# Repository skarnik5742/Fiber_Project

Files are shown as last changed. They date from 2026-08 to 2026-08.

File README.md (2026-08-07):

| Supported Targets | ESP32 | ESP32-C2 | ESP32-C3 | ESP32-C5 | ESP32-C6 | ESP32-C61 | ESP32-H2 | ESP32-H21 | ESP32-H4 | ESP32-P4 | ESP32-S2 | ESP32-S3 |
| --- | ----- | --- | --- | --- | --- | --- | --- | --- | --- | --- | --- | --- |

# Blink Example

(See the README.md file in the upper level 'examples' directory for more information about examples.)

This example demonstrates how to blink a LED by using the GPIO driver or using the [led_strip](https://components.espressif.com/component/espressif/led_strip) library if the LED is addressable e.g. [WS2812](https://cdn-shop.adafruit.com/datasheets/WS2812B.pdf). The `led_strip` library is installed via [component manager](main/idf_component.yml).

## How to Use Example

Before project configuration and build, be sure to set the correct chip target using `idf.py set-target <chip_name>`.

### Hardware Required

* A development board with normal LED or addressable LED on-board (e.g., ESP32-S3-DevKitC, ESP32-C6-DevKitC etc.)
* A USB cable for Power supply and programming

See [Development Boards](https://www.espressif.com/en/products/devkits) for more information about it.

### Configure the Project

Open the project configuration menu (`idf.py menuconfig`).

In the `Example Configuration` menu:

* Select the LED type in the `Blink LED type` option.
  * Use `GPIO` for regular LED
  * Use `LED strip` for addressable LED
* If the LED type is `LED strip`, select the backend peripheral
  * `RMT` is only available for ESP targets with RMT peripheral supported
  * `SPI` is available for all ESP targets
* Set the GPIO number used for the signal in the `Blink GPIO number` option.
* Set the blinking period in the `Blink period in ms` option.

### Build and Flash

Run `idf.py -p PORT flash monitor` to build, flash and monitor the project.

(To exit the serial monitor, type ``Ctrl-]``.)

See the [Getting Started Guide](https://docs.espressif.com/projects/esp-idf/en/latest/get-started/index.html) for full steps to configure and use ESP-IDF to build projects.

## Example Output

As you run the example, you will see the LED blinking, according to the previously defined period. For the addressable LED, you can also change the LED color by setting the `led_strip_set_pixel(led_strip, 0, 16, 16, 16);` (LED Strip, Pixel Number, Red, Green, Blue) with values from 0 to 255 in the [source file](main/blink_example_main.c).

```text
I (315) example: Example configured to blink addressable LED!
I (325) example: Turning the LED OFF!
I (1325) example: Turning the LED ON!
I (2325) example: Turning the LED OFF!
I (3325) example: Turning the LED ON!
I (4325) example: Turning the LED OFF!
I (5325) example: Turning the LED ON!
I (6325) example: Turning the LED OFF!
I (7325) example: Turning the LED ON!
I (8325) example: Turning the LED OFF!
```

Note: The color order could be different according to the LED model.

The pixel number indicates the pixel position in the LED strip. For a single LED, use 0.

## Troubleshooting

* If the LED isn't blinking, check the GPIO or the LED type selection in the `Example Configuration` menu.

For any technical queries, please open an [issue](https://github.com/espressif/esp-idf/issues) on GitHub. We will get back to you soon.

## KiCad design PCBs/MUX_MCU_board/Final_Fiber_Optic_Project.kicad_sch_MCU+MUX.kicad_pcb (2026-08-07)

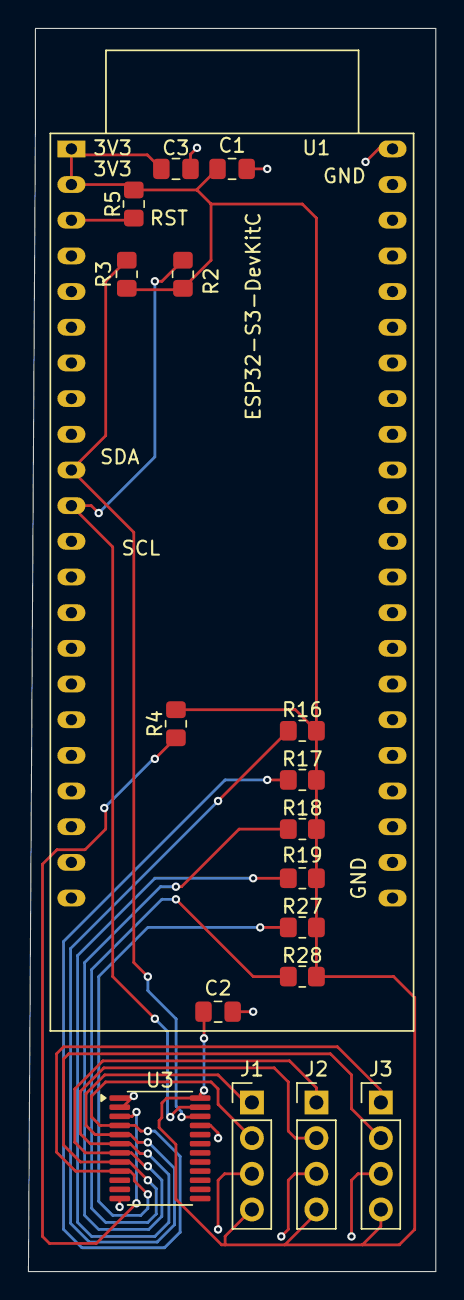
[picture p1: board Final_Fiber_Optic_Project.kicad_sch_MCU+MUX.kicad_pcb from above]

Board: 2 copper layers, 29.0 x 88.5 mm, 18 parts (0 on the bottom side), 12 nets.

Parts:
C1, C2: 100nF; C_0805_2012Metric_Pad1.18x1.45mm_HandSolder
C3: 10uF; C_0805_2012Metric_Pad1.18x1.45mm_HandSolder
J1, J2, J3: Conn_01x04_Socket; PinHeader_1x04_P2.54mm_Vertical
R2, R3, R4, R5: 10kOhm; R_0805_2012Metric_Pad1.20x1.40mm_HandSolder
R16, R17, R18, R19, R27, R28: 2kOhm; R_0805_2012Metric_Pad1.20x1.40mm_HandSolder
U1: ESP32-S3-DevKitC
U3: TCA9548APWR; TSSOP-24_4.4x7.8mm_P0.65mm

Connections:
GND: C1.2, C2.2, C3.2, J1.3, J2.3, J3.3, U1.22 (GND), U1.23 (GND), U1.24 (GND), U1.44 (GND), U3.1 (A0), U3.2 (A1), U3.12 (GND), U3.21 (A2)
unnamed: J1.1, R16.1, U3.5 (SC0)
unnamed: J1.2, R17.2, U3.4 (SD0)
unnamed: C1.1, C2.1, C3.1, J1.4, J2.4, J3.4, R2.1, R3.1, R4.1, R5.1, R16.2, R17.1, R18.1, R19.2, R27.2, R28.2, U1.1 (3V3), U1.2 (3V3), U3.24 (VCC)
unnamed: J2.1, R18.2, U3.7 (SC1)
unnamed: J2.2, R19.1, U3.6 (SD1)
unnamed: J3.1, R27.1, U3.9 (SC2)
unnamed: J3.2, R28.1, U3.8 (SD2)
unnamed: R5.2, U1.3 (CHIP_PU)
unnamed: R3.2, U1.10 (GPIO17/ADC2_CH6), U3.22 (SCL)
unnamed: R2.2, U1.11 (GPIO18/ADC2_CH7), U3.23 (SDA)
unnamed: R4.2, U3.3 (~RESET)

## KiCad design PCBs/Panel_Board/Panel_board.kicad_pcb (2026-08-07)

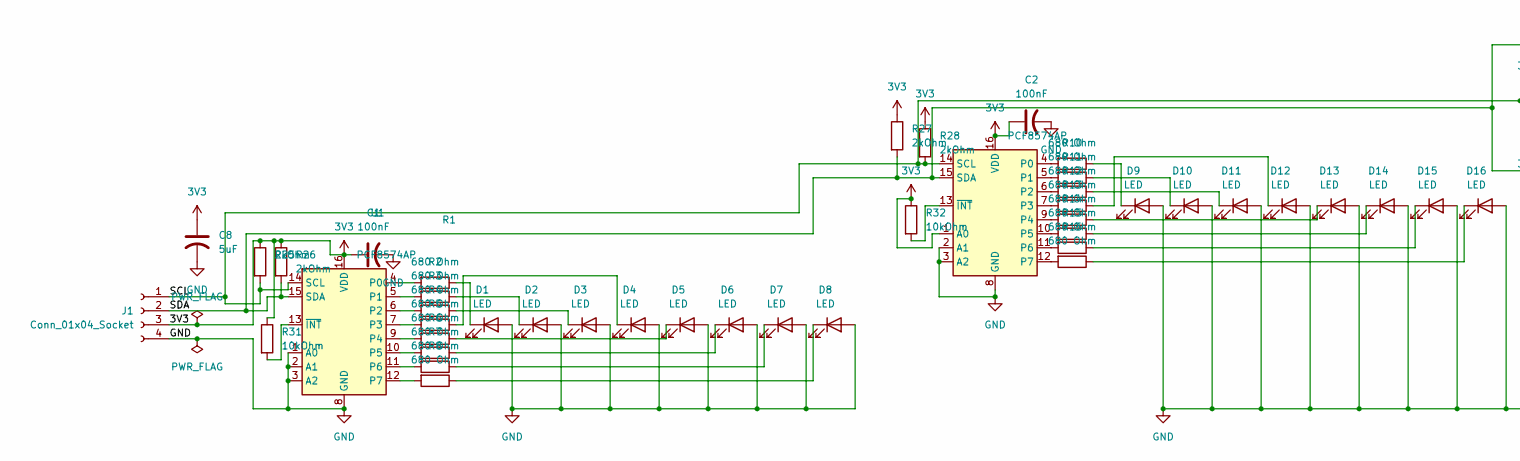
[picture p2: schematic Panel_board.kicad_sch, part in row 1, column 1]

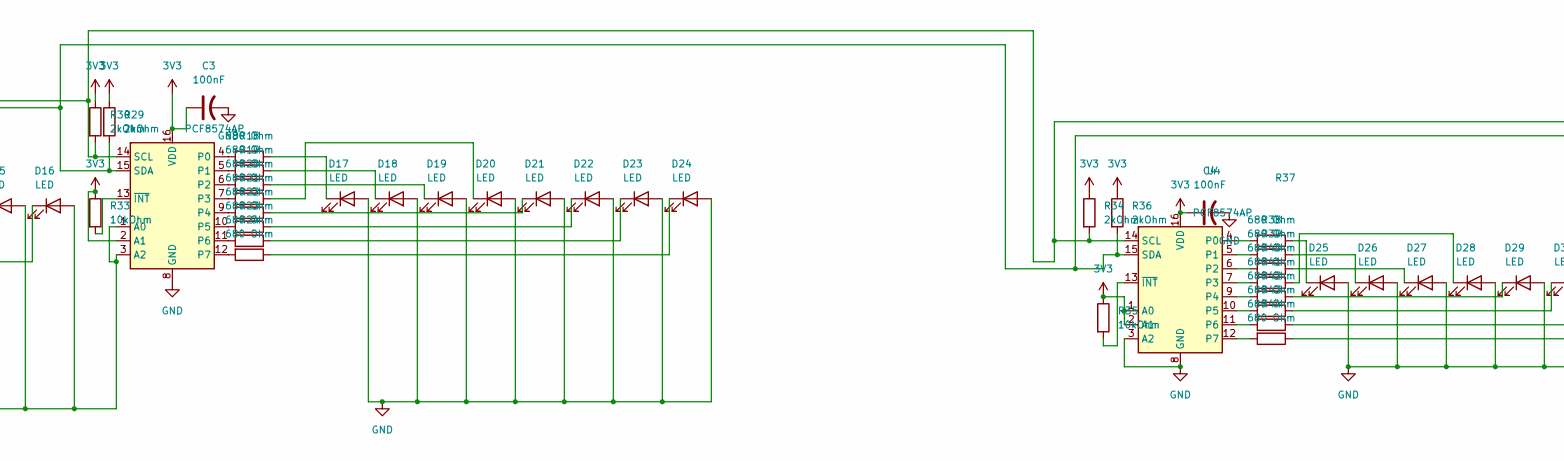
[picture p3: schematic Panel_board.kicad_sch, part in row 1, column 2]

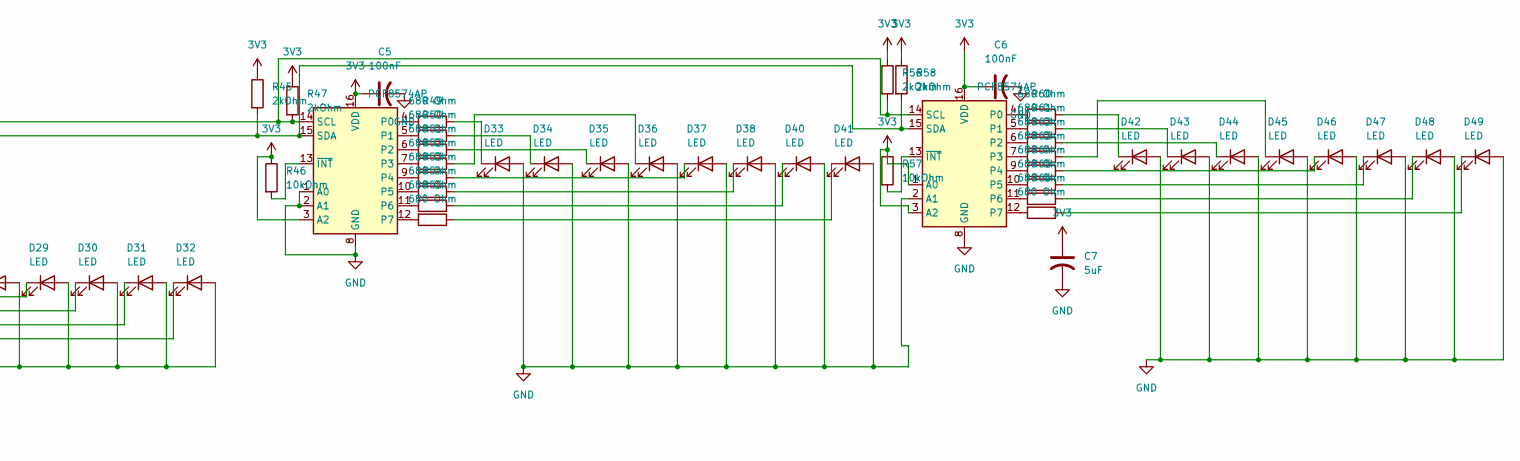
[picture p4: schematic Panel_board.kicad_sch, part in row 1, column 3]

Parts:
C1, C2, C3, C4, C5, C6: 100nF; C_0805_2012Metric_Pad1.18x1.45mm_HandSolder
C7, C8: 5uF; C_0805_2012Metric_Pad1.18x1.45mm_HandSolder
D1, D2, D3, D4, D5, D6, D7, D8, D9, D10, D11, D12, D13, D14, D15, D16, D17, D18, D19, D20, D21, D22, D23, D24, D25, D26, D27, D28, D29, D30, D31, D32, D33, D34, D35, D36, D37, D38, D40, D41, D42, D43, D44, D45, D46, D47, D48, D49: LED; LED_D5.0mm
J1: Conn_01x04_Socket; PinHeader_1x04_P2.54mm_Vertical
R1, R2, R3, R4, R5, R6, R7, R8, R9, R10, R11, R12, R13, R14, R15, R16, R17, R18, R19, R20, R21, R22, R23, R24, R37, R38, R39, R40, R41, R42, R43, R44, R48, R49, R50, R51, R52, R53, R54, R55, R59, R60, R61, R62, R63, R64, R65, R66: 680 Ohm; R_0805_2012Metric_Pad1.20x1.40mm_HandSolder
R25, R26, R27, R28, R29, R30, R34, R36, R45, R47, R56, R58: 2kOhm; R_0805_2012Metric_Pad1.20x1.40mm_HandSolder
R31, R32, R33, R35, R46, R57: 10kOhm; R_0805_2012Metric_Pad1.20x1.40mm_HandSolder
U1, U2, U3, U4, U5, U6: PCF8574AP; DIP-16_W7.62mm

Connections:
3V3: C1.1, C2.1, C3.1, C4.1, C5.1, C6.1, C7.1, C8.1, J1.3, R25.1, R26.1, R27.1, R28.1, R29.1, R30.1, R31.1, R32.1, R33.1, R34.1, R35.1, R36.1, R45.1, R46.1, R47.1, R56.1, R57.1, R58.1, U1.16 (VDD), U2.1 (A0), U2.16 (VDD), U3.2 (A1), U3.16 (VDD), U4.1 (A0), U4.2 (A1), U4.16 (VDD), U5.3 (A2), U5.16 (VDD), U6.1 (A0), U6.3 (A2), U6.16 (VDD)
/SCL: J1.1, R25.2, R28.2, R30.2, R34.2, R47.2, R56.2, U1.14 (SCL), U2.14 (SCL), U3.14 (SCL), U4.14 (SCL), U5.14 (SCL), U6.14 (SCL)
/SDA: J1.2, R26.2, R27.2, R29.2, R36.2, R45.2, R58.2, U1.15 (SDA), U2.15 (SDA), U3.15 (SDA), U4.15 (SDA), U5.15 (SDA), U6.15 (SDA)
GND: C1.2, C2.2, C3.2, C4.2, C5.2, C6.2, C7.2, C8.2, D1.2 (A), D2.2 (A), D3.2 (A), D4.2 (A), D5.2 (A), D6.2 (A), D7.2 (A), D8.2 (A), D9.2 (A), D10.2 (A), D11.2 (A), D12.2 (A), D13.2 (A), D14.2 (A), D15.2 (A), D16.2 (A), D17.2 (A), D18.2 (A), D19.2 (A), D20.2 (A), D21.2 (A), D22.2 (A), D23.2 (A), D24.2 (A), D25.2 (A), D26.2 (A), D27.2 (A), D28.2 (A), D29.2 (A), D30.2 (A), D31.2 (A), D32.2 (A), D33.2 (A), D34.2 (A), D35.2 (A), D36.2 (A), D37.2 (A), D38.2 (A), D40.2 (A), D41.2 (A), D42.2 (A), D43.2 (A), D44.2 (A), D45.2 (A), D46.2 (A), D47.2 (A), D48.2 (A), D49.2 (A), J1.4, U1.1 (A0), U1.2 (A1), U1.3 (A2), U1.8 (GND), U2.2 (A1), U2.3 (A2), U2.8 (GND), U3.1 (A0), U3.3 (A2), U3.8 (GND), U4.3 (A2), U4.8 (GND), U5.1 (A0), U5.2 (A1), U5.8 (GND), U6.2 (A1), U6.8 (GND)
unnamed: D1.1 (K), R1.1
unnamed: D2.1 (K), R2.1
unnamed: D3.1 (K), R3.1
unnamed: D4.1 (K), R4.1
unnamed: D5.1 (K), R5.1
unnamed: D6.1 (K), R6.1
unnamed: D7.1 (K), R7.1
unnamed: D8.1 (K), R8.1
unnamed: D9.1 (K), R9.1
unnamed: D10.1 (K), R10.1
unnamed: D11.1 (K), R11.1
unnamed: D12.1 (K), R12.1
unnamed: D13.1 (K), R13.1
unnamed: D14.1 (K), R14.1
unnamed: D15.1 (K), R15.1
unnamed: D16.1 (K), R16.1
unnamed: D17.1 (K), R17.1
unnamed: D18.1 (K), R18.1
unnamed: D19.1 (K), R19.1
unnamed: D20.1 (K), R20.1
unnamed: D21.1 (K), R21.1
unnamed: D22.1 (K), R22.1
unnamed: D23.1 (K), R23.1
unnamed: D24.1 (K), R24.1
unnamed: D25.1 (K), R37.1
unnamed: D26.1 (K), R38.1
unnamed: D27.1 (K), R39.1
unnamed: D28.1 (K), R40.1
unnamed: D29.1 (K), R41.1
unnamed: D30.1 (K), R42.1
unnamed: D31.1 (K), R43.1
unnamed: D32.1 (K), R44.1
unnamed: D33.1 (K), R48.1
unnamed: D34.1 (K), R49.1
unnamed: D35.1 (K), R50.1
unnamed: D36.1 (K), R51.1
unnamed: D37.1 (K), R52.1
unnamed: D38.1 (K), R53.1
unnamed: D40.1 (K), R54.1
unnamed: D41.1 (K), R55.1
unnamed: D42.1 (K), R59.1
unnamed: D43.1 (K), R60.1
unnamed: D44.1 (K), R61.1
unnamed: D45.1 (K), R62.1
unnamed: D46.1 (K), R63.1
unnamed: D47.1 (K), R64.1
unnamed: D48.1 (K), R65.1
unnamed: D49.1 (K), R66.1
unnamed: R1.2, U1.4 (P0)
unnamed: R2.2, U1.5 (P1)
unnamed: R3.2, U1.6 (P2)
unnamed: R4.2, U1.7 (P3)
unnamed: R5.2, U1.9 (P4)
unnamed: R6.2, U1.10 (P5)
unnamed: R7.2, U1.11 (P6)
unnamed: R8.2, U1.12 (P7)
unnamed: R31.2, U1.13 (~INT)
unnamed: R9.2, U2.4 (P0)
unnamed: R10.2, U2.5 (P1)
unnamed: R11.2, U2.6 (P2)
unnamed: R12.2, U2.7 (P3)
unnamed: R13.2, U2.9 (P4)
unnamed: R14.2, U2.10 (P5)
unnamed: R15.2, U2.11 (P6)
unnamed: R16.2, U2.12 (P7)
unnamed: R32.2, U2.13 (~INT)
unnamed: R17.2, U3.4 (P0)
unnamed: R18.2, U3.5 (P1)
unnamed: R19.2, U3.6 (P2)
unnamed: R20.2, U3.7 (P3)
unnamed: R21.2, U3.9 (P4)
unnamed: R22.2, U3.10 (P5)
unnamed: R23.2, U3.11 (P6)
unnamed: R24.2, U3.12 (P7)
unnamed: R33.2, U3.13 (~INT)
unnamed: R37.2, U4.4 (P0)
unnamed: R38.2, U4.5 (P1)
unnamed: R39.2, U4.6 (P2)
unnamed: R40.2, U4.7 (P3)
unnamed: R41.2, U4.9 (P4)
unnamed: R42.2, U4.10 (P5)
unnamed: R43.2, U4.11 (P6)
unnamed: R44.2, U4.12 (P7)
unnamed: R35.2, U4.13 (~INT)
unnamed: R48.2, U5.4 (P0)
unnamed: R49.2, U5.5 (P1)
unnamed: R50.2, U5.6 (P2)
unnamed: R51.2, U5.7 (P3)
unnamed: R52.2, U5.9 (P4)
unnamed: R53.2, U5.10 (P5)
unnamed: R54.2, U5.11 (P6)
unnamed: R55.2, U5.12 (P7)
unnamed: R46.2, U5.13 (~INT)
unnamed: R59.2, U6.4 (P0)
unnamed: R60.2, U6.5 (P1)
unnamed: R61.2, U6.6 (P2)
unnamed: R62.2, U6.7 (P3)
unnamed: R63.2, U6.9 (P4)
unnamed: R64.2, U6.10 (P5)
unnamed: R65.2, U6.11 (P6)
unnamed: R66.2, U6.12 (P7)
unnamed: R57.2, U6.13 (~INT)

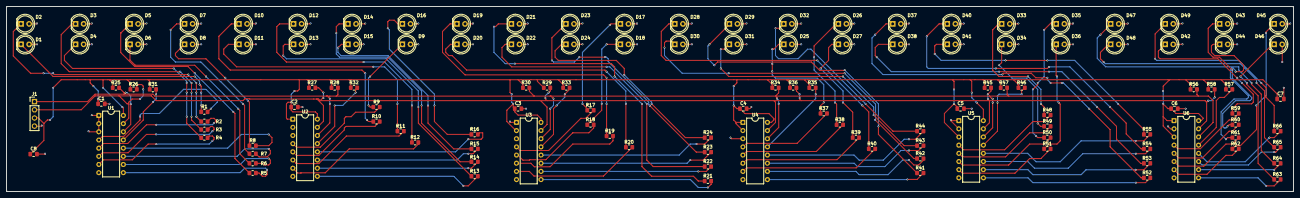
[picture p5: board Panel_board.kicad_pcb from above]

Board: 2 copper layers, 400.0 x 57.5 mm, 129 parts (0 on the bottom side), 106 nets.

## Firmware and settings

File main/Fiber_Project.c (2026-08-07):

/* Blink Example

   This example code is in the Public Domain (or CC0 licensed, at your option.)

   Unless required by applicable law or agreed to in writing, this
   software is distributed on an "AS IS" BASIS, WITHOUT WARRANTIES OR
   CONDITIONS OF ANY KIND, either express or implied.
*/
#include "driver/gpio.h"
#include "led_strip.h"
#include "sdkconfig.h"

#include <stdio.h>
#include <string.h>
#include <stdlib.h>

#include "freertos/FreeRTOS.h"
#include "freertos/task.h"

#include "driver/uart.h"
#include "driver/i2c_master.h"

#include "esp_log.h"
#include "esp_check.h"

// ===================================================
// CONFIGURATION
// ===================================================

#define TAG "LED_CONTROLLER"

#define I2C_SDA_PIN           17
#define I2C_SCL_PIN           18

#define I2C_PORT_NUM          0
#define I2C_FREQ_HZ           100000

#define TCA9548A_ADDRESS      0x70

#define NUM_CHANNELS          3
#define NUM_EXPANDERS         6
#define LEDS_PER_EXPANDER     8
#define LEDS_PER_CHANNEL      48
#define TOTAL_LEDS            144

// ===================================================
// TYPES
// ===================================================

typedef struct
{
    uint8_t mux_channel;
    uint8_t expander_index;
    uint8_t pcf_address;
    uint8_t pcf_pin;
} led_location_t;

// ===================================================
// GLOBALS
// ===================================================

static i2c_master_bus_handle_t bus_handle;

static i2c_master_dev_handle_t mux_handle;

static i2c_master_dev_handle_t pcf_handles[NUM_CHANNELS][NUM_EXPANDERS];

static uint8_t pcf_states[NUM_CHANNELS][NUM_EXPANDERS];

// ===================================================
// I2C INITIALIZATION
// ===================================================

static void init_i2c(void)
{
    i2c_master_bus_config_t bus_cfg = {
        .clk_source = I2C_CLK_SRC_DEFAULT,
        .i2c_port = I2C_PORT_NUM,
        .sda_io_num = I2C_SDA_PIN,
        .scl_io_num = I2C_SCL_PIN,
        .glitch_ignore_cnt = 7,
        .flags.enable_internal_pullup = true,
    };

    ESP_ERROR_CHECK(
        i2c_new_master_bus(&bus_cfg, &bus_handle));

    ESP_LOGI(TAG, "I2C initialized");
}

// ===================================================
// TCA9548A
// ===================================================

static void init_mux(void)
{
    i2c_device_config_t mux_cfg = {
        .dev_addr_length = I2C_ADDR_BIT_LEN_7,
        .device_address = TCA9548A_ADDRESS,
        .scl_speed_hz = I2C_FREQ_HZ,
    };

    ESP_ERROR_CHECK(
        i2c_master_bus_add_device(
            bus_handle,
            &mux_cfg,
            &mux_handle));

    ESP_LOGI(TAG, "MUX initialized");
}

static void mux_select_channel(uint8_t channel)
{
    if (channel > 7) {
        return;
    }

    uint8_t cmd = (1 << channel);

    ESP_ERROR_CHECK(
        i2c_master_transmit(
            mux_handle,
            &cmd,
            1,
            -1));
}

// ===================================================
// PCF8574A
// ===================================================

static void init_pcf_devices(void)
{
    uint8_t addresses[NUM_EXPANDERS] = {
        0x38,
        0x39,
        0x3A,
        0x3B,
        0x3C,
        0x3D
    };

    for (int channel = 0; channel < NUM_CHANNELS; channel++) {

        mux_select_channel(channel);

        for (int expander = 0; expander < NUM_EXPANDERS; expander++) {

            i2c_device_config_t cfg = {
                .dev_addr_length = I2C_ADDR_BIT_LEN_7,
                .device_address = addresses[expander],
                .scl_speed_hz = I2C_FREQ_HZ,
            };

            ESP_ERROR_CHECK(
                i2c_master_bus_add_device(
                    bus_handle,
                    &cfg,
                    &pcf_handles[channel][expander]));

            pcf_states[channel][expander] = 0x00;

            ESP_ERROR_CHECK(
                i2c_master_transmit(
                    pcf_handles[channel][expander],
                    &pcf_states[channel][expander],
                    1,
                    -1));
        }
    }

    ESP_LOGI(TAG, "PCF8574A devices initialized");
}

// ===================================================
// LED MAPPING
// ===================================================

static led_location_t get_led_location(uint16_t led_num)
{
    led_location_t loc = {0};

    uint16_t index = led_num - 1;

    loc.mux_channel = index / LEDS_PER_CHANNEL;

    uint8_t channel_position =
        index % LEDS_PER_CHANNEL;

    loc.expander_index =
        channel_position / LEDS_PER_EXPANDER;

    loc.pcf_address =
        0x38 + loc.expander_index;

    loc.pcf_pin =
        channel_position % LEDS_PER_EXPANDER;

    return loc;
}

// ===================================================
// LED CONTROL
// ===================================================

static void set_led_on(uint16_t led_num)
{
    if ((led_num < 1) || (led_num > TOTAL_LEDS)) {
        return;
    }

    led_location_t loc =
        get_led_location(led_num);

    mux_select_channel(loc.mux_channel);

    pcf_states[loc.mux_channel]
              [loc.expander_index]
        |= (1 << loc.pcf_pin);

    ESP_ERROR_CHECK(
        i2c_master_transmit(
            pcf_handles
                [loc.mux_channel]
                [loc.expander_index],
            &pcf_states
                [loc.mux_channel]
                [loc.expander_index],
            1,
            -1));
}

static void set_led_off(uint16_t led_num)
{
    if ((led_num < 1) || (led_num > TOTAL_LEDS)) {
        return;
    }

    led_location_t loc =
        get_led_location(led_num);

    mux_select_channel(loc.mux_channel);

    pcf_states[loc.mux_channel]
              [loc.expander_index]
        &= ~(1 << loc.pcf_pin);

    ESP_ERROR_CHECK(
        i2c_master_transmit(
            pcf_handles
                [loc.mux_channel]
                [loc.expander_index],
            &pcf_states
                [loc.mux_channel]
                [loc.expander_index],
            1,
            -1));
}

static void all_on(void)
{
    for (int led = 1; led <= TOTAL_LEDS; led++) {
        set_led_on(led);
    }
}

static void all_off(void)
{
    for (int led = 1; led <= TOTAL_LEDS; led++) {
        set_led_off(led);
    }
}

// ===================================================
// UART COMMANDS
// ===================================================

static void process_command(char *cmd)
{
    if (strncmp(cmd, "all_on", 6) == 0) {

        all_on();

        printf("ALL LEDs ON\r\n");
        return;
    }

    if (strncmp(cmd, "all_off", 7) == 0) {

        all_off();

        printf("ALL LEDs OFF\r\n");
        return;
    }

    if (strncmp(cmd, "on ", 3) == 0) {

        int led = atoi(&cmd[3]);

        set_led_on(led);

        printf("LED %d ON\r\n", led);
        return;
    }

    if (strncmp(cmd, "off ", 4) == 0) {

        int led = atoi(&cmd[4]);

        set_led_off(led);

        printf("LED %d OFF\r\n", led);
        return;
    }

    printf("Unknown command\r\n");
}

// ===================================================
// APP MAIN
// ===================================================

void app_main(void)
{
    init_i2c();

    init_mux();

    init_pcf_devices();

    printf("\r\n");
    printf("Commands:\r\n");
    printf("on 57\r\n");
    printf("off 57\r\n");
    printf("all_on\r\n");
    printf("all_off\r\n");
    printf("\r\n");

    char rx_buffer[64];

    while (1) {

        if (fgets(rx_buffer,
                  sizeof(rx_buffer),
                  stdin) != NULL) {

            rx_buffer[strcspn(rx_buffer,
                              "\r\n")] = 0;

            process_command(rx_buffer);
        }

        vTaskDelay(pdMS_TO_TICKS(10));
    }
}

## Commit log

2026-08-07 Initial ESP32-S3 firmware project
2026-08-07 PCB Folders
2026-08-07 Create PCB
2026-08-07 added PCBs file
2026-08-07 Add KiCad board files
    [Final_Fiber_Optic_Project.kicad_sch_MCU+MUX.kicad_pcb, Final_Fiber_Optic_Project.kicad_sch_MCU+MUX.kicad_sch, Panel_board.kicad_pcb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]
